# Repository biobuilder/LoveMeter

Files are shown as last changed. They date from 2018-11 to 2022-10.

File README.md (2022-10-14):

# LoveMeter
Love Meter Public Repository
Created by Damon Printz, November 11 2018

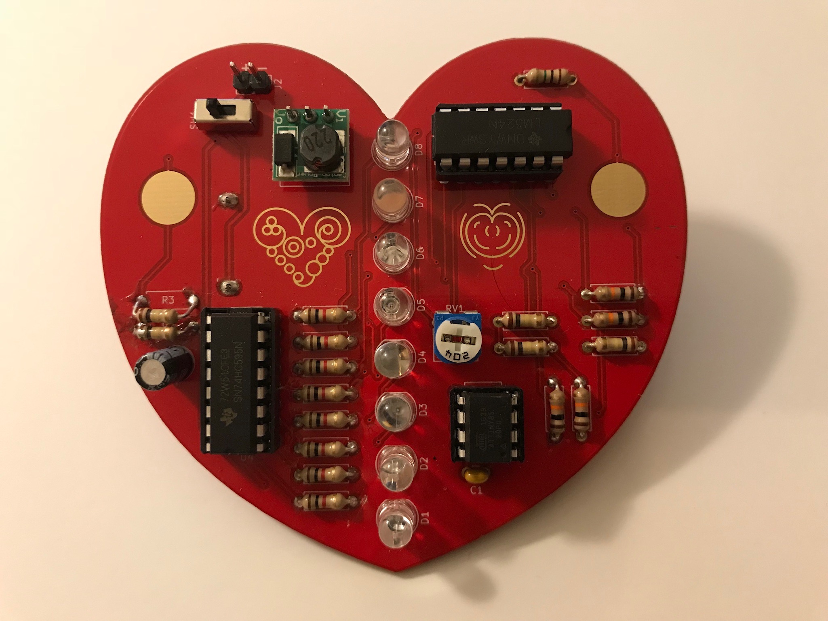
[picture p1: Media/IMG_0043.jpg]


The Love Meter is a galvanic-sensing, heart-warming educational kit for any electronic enthusiast (and their partner).  To measure love, a pair of users touch the gold-plated terminals with opposing fingers while in contact with each other.  The resulting closed circuit will measure the “conductive strength” of their feelings.  The stronger the feelings, the more LEDs will light up.  This is a very fine-tuned process, guaranteed to give you 100% accurate results.  Alternatively, if you are alone, you can see how much you love yourself.  You're at least one person you can't live without.  

Please see the Love Meter Assembly Video.
https://www.youtube.com/watch?v=fPo8kFWzP4U&t=6s

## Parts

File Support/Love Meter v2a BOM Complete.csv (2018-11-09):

Love Meter v2a Bill of Materials - Damon Printz |  |  | November 2018
ID | Designation | Value | Footprint | Part No. | Description | Manufacturer | Provider | Comment
1 | C1 | 0.1uF | 2.5mm Thru Hole | BC1072TR-ND | CAP CER 1000PF 50V X7R RADIAL | Vishay BC Components | Digikey | Ceramic Capacitor
2 | C2 | 1uF | 5mm OD x 2mm pitch | ESK105M050AC3AA | CAP ALUM 1UF 20% 50V RADIAL | KEMET | Digikey | Electrolytic Polarized Capacitor
3 | D1 | Blue | 5mm Thru Hole | WP7113QBC/D | LED BLUE CLEAR T-1 3/4 T/H | Kingbright | Digikey | 5mm, Round dome top, clear casing, 15 - 45 deg field of view, 8.5 - 8.8 mm tall, 1000 - 8000 mcd, 0 - 30 mA, < 4V Vf
4 | D2 | Green | 5mm Thru Hole | WP7113LZGCK | LED GREEN CLEAR T-1 3/4 T/H | Kingbright | Digikey
5 | D3 | Yellow | 5mm Thru Hole | WP7113SYC | LED YELLOW CLEAR T-1 3/4 T/H | Kingbright | Digikey
6 | D4 | Orange | 5mm Thru Hole | SSL-LX5093SOC | LED ORANGE CLEAR T-1 3/4 T/H | Lumex Opto/Components Inc | Digikey
7 | D5 | Red | 5mm Thru Hole | SSL-LX5093SRC/E | LED RED CLEAR T-1 3/4 T/H | Lumex Opto/Components Inc | Digikey
8 | D6 | Purple/Violet | 5mm Thru Hole | SSL-LX5093VC | LED PURPLE CLEAR T-1 3/4 T/H | Lumex Opto/Components Inc | Digikey
9 | D7 | Pink | 5mm Thru Hole | SSL-LX5093PC | LED PINK CLEAR T-1 3/4 T/H | Lumex Opto/Components Inc | Digikey
10 | D8 | White | 5mm Thru Hole | SLX-LX5093UWC/C | LED WHITE CLEAR T-1 3/4 T/H | Lumex Opto/Components Inc | Digikey
11 | J1 |  | 2x12.7mm Thru Hole | 2468 | BATTERY HOLDER AAA 2 CELL PC PIN | Keystone Electronics | Digikey | Note: May be exchanged for a AAA holder with actual wires instead of prongs
12 | J2 | DNP |  |  | DNP |  |  | Do Not Place
13 | J3 |  | 3x2.54mm | 61300311121 | CONN HEADER 3 POS 2.54 | Wurth Electronics Inc | Digikey | Headers for U1
14 | R4 | DNP |  |  | DNP |  |  | Do Not Place
15 | R1 | 1M | 6.3mm Thru Hole | CF14JT1M00 | RES 1M OHM 1/4W 5% AXIAL | Stackpole Electronics Inc | Digikey | 5% Resistor
16 | R2, R3, R5, R6 | 100k | 6.3mm Thru Hole | CF14JT100K | RES 100K OHM 1/4W 5% AXIAL | Stackpole Electronics Inc | Digikey | 5% Resistor
17 | R7, R8, R17, R18 | 10k | 6.3mm Thru Hole | CF14JT10K0 | RES 10K OHM 1/4W 5% AXIAL | Stackpole Electronics Inc | Digikey | 5% Resistor
18 | R9, R10, R11, R12, R13, R14, R15, R16 | 1k | 6.3mm Thru Hole | CF14JT1K00 | RES 1K OHM 1/4W 5% AXIAL | Stackpole Electronics Inc | Digikey | 5% Resistor
19 | RV1 | 200k | 5x5mm Thru Hole | 3306F-1-204 | TRIMMER 200K OHM 0.2W PC PIN TOP | Bourns Inc | Digikey | Trimpot Resistor
20 | SW1 |  | 3x2.54mm | EG1218 | SWITCH SLIDE SPDT 200MA 30V | E-Switch | Digikey | SPDT switch
21 | U1 |  | 3x2.54mm |  |  |  | Alibaba | 5V DC-DC Boost Regulator
22 | U2 |  | DIP-8 | ATTINY85-20PU | IC MCU 8BIT 8KB FLASH 8DIP | Microchip Technology | Digikey | Microprocessor
23 | U3 |  | DIP-14 | LM324N | IC OPAMP GP 1.2MHZ 14DIP | Texas Instruments | Digikey | Op Amps
24 | U4 |  | DIP-16 | SN74HC595N | IC 8-BIT SHIFT REGISTER 16-DIP | Texas Instruments | Digikey | Shift Register
25 | X1 |  | DIP-8 | A 08-LC-TT | CONN IC DIP SOCKET 8POS TIN | Assmann WSW Components | Digikey | IC Socket
26 | X2 |  | DIP-14 | A 14-LC-TT | CONN IC DIP SOCKET 14POS TIN | Assmann WSW Components | Digikey | IC Socket
27 | X3 |  | DIP-16 | A 16-LC-TT | CONN IC DIP SOCKET 16POS TIN | Assmann WSW Components | Digikey | IC Socket
28 | F1 |  |  | 31201527 | 3M 4008 series, 1" wide, 1/8" thick Urethane Double-Sided Tape | 3M | Grainger | Double sided foam tape
29 | F2 |  |  |  | 2 layer, FR4, Red soldermask with ENIG finish |  |  | PCB Board

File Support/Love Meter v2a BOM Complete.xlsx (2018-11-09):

Love Meter v2a Bill of Materials - Damon Printz |  |  | 2018-11-01
ID | Designation | Value | Footprint | Part No. | Description | Manufacturer | Provider | Comment
1 | C1 | 0.1uF | 2.5mm Thru Hole | BC1072TR-ND | CAP CER 1000PF 50V X7R RADIAL | Vishay BC Components | Digikey (https://www.digikey.com/product-detail/en/vishay-bc-components/K102K15X7RF5TL2/BC1072TR-ND/286526) | Ceramic Capacitor
2 | C2 | 1uF | 5mm OD x 2mm pitch | ESK105M050AC3AA | CAP ALUM 1UF 20% 50V RADIAL | KEMET | Digikey (https://www.digikey.com/product-detail/en/kemet/ESK105M050AC3AA/399-6596-ND/3083011) | Electrolytic Polarized Capacitor
3 | D1 | Blue | 5mm Thru Hole | WP7113QBC/D | LED BLUE CLEAR T-1 3/4 T/H | Kingbright | Digikey (https://www.digikey.com/product-detail/en/kingbright/WP7113QBC-D/754-1489-ND/2261460) | 5mm, Round dome top, clear casing, 15 - 45 deg field of view, 8.5 - 8.8 mm tall, 1000 - 8000 mcd, 0 - 30 mA, < 4V Vf
4 | D2 | Green | 5mm Thru Hole | WP7113LZGCK | LED GREEN CLEAR T-1 3/4 T/H | Kingbright | Digikey (https://www.digikey.com/product-detail/en/kingbright/WP7113LZGCK/754-1920-ND/5177421)
5 | D3 | Yellow | 5mm Thru Hole | WP7113SYC | LED YELLOW CLEAR T-1 3/4 T/H | Kingbright | Digikey (https://www.digikey.com/product-detail/en/kingbright/WP7113SYC/754-1280-ND/1747679)
6 | D4 | Orange | 5mm Thru Hole | SSL-LX5093SOC | LED ORANGE CLEAR T-1 3/4 T/H | Lumex Opto/Components Inc | Digikey (https://www.digikey.com/product-detail/en/lumex-opto-components-inc/SSL-LX5093SOC/67-1113-ND/270911)
7 | D5 | Red | 5mm Thru Hole | SSL-LX5093SRC/E | LED RED CLEAR T-1 3/4 T/H | Lumex Opto/Components Inc | Digikey (https://www.digikey.com/product-detail/en/lumex-opto-components-inc/SSL-LX5093SRC-E/67-1612-ND/334590)
8 | D6 | Purple/Violet | 5mm Thru Hole | SSL-LX5093VC | LED PURPLE CLEAR T-1 3/4 T/H | Lumex Opto/Components Inc | Digikey (https://www.digikey.com/products/en/optoelectronics/led-indication-discrete/105)
9 | D7 | Pink | 5mm Thru Hole | SSL-LX5093PC | LED PINK CLEAR T-1 3/4 T/H | Lumex Opto/Components Inc | Digikey
10 | D8 | White | 5mm Thru Hole | SLX-LX5093UWC/C | LED WHITE CLEAR T-1 3/4 T/H | Lumex Opto/Components Inc | Digikey (https://www.digikey.com/product-detail/en/lumex-opto-components-inc/SLX-LX5093UWC-C/67-1691-ND/754532)
11 | J1 |  | 2x12.7mm Thru Hole | 2468 | BATTERY HOLDER AAA 2 CELL PC PIN | Keystone Electronics | Digikey (https://www.digikey.com/product-detail/en/keystone-electronics/2468/36-2468-ND/303817) | Note: May be exchanged for a AAA holder with actual wires instead of prongs
12 | J2 | DNP |  |  | DNP |  |  | Do Not Place
13 | J3 |  | 3x2.54mm | 61300311121 | CONN HEADER 3 POS 2.54 | Wurth Electronics Inc | Digikey (https://www.digikey.com/product-detail/en/wurth-electronics-inc/61300311121/732-5316-ND/4846825) | Headers for U1
14 | R4 | DNP |  |  | DNP |  |  | Do Not Place
15 | R1 | 1M | 6.3mm Thru Hole | CF14JT1M00 | RES 1M OHM 1/4W 5% AXIAL | Stackpole Electronics Inc | Digikey (https://www.digikey.com/product-detail/en/stackpole-electronics-inc/CF14JT1M00/CF14JT1M00TR-ND/1741316) | 5% Resistor
16 | R2, R3, R5, R6 | 100k | 6.3mm Thru Hole | CF14JT100K | RES 100K OHM 1/4W 5% AXIAL | Stackpole Electronics Inc | Digikey (https://www.digikey.com/product-detail/en/stackpole-electronics-inc/CF14JT100K/CF14JT100KTR-ND/1741263) | 5% Resistor
17 | R7, R8, R17, R18 | 10k | 6.3mm Thru Hole | CF14JT10K0 | RES 10K OHM 1/4W 5% AXIAL | Stackpole Electronics Inc | Digikey (https://www.digikey.com/product-detail/en/stackpole-electronics-inc/CF14JT10K0/CF14JT10K0TR-ND/1741265) | 5% Resistor
18 | R9, R10, R11, R12, R13, R14, R15, R16 | 1k | 6.3mm Thru Hole | CF14JT1K00 | RES 1K OHM 1/4W 5% AXIAL | Stackpole Electronics Inc | Digikey (https://www.digikey.com/product-detail/en/stackpole-electronics-inc/CF14JT1K00/CF14JT1K00TR-ND/1741314) | 5% Resistor
19 | RV1 | 200k | 5x5mm Thru Hole | 3306F-1-204 | TRIMMER 200K OHM 0.2W PC PIN TOP | Bourns Inc | Digikey (https://www.digikey.com/product-detail/en/bourns-inc/3306F-1-204/3306F-204-ND/84718) | Trimpot Resistor
20 | SW1 |  | 3x2.54mm | EG1218 | SWITCH SLIDE SPDT 200MA 30V | E-Switch | Digikey (https://www.digikey.com/product-detail/en/e-switch/EG1218/EG1903-ND/101726) | SPDT switch
21 | U1 |  | 3x2.54mm |  |  |  | Alibaba (https://wholesaler.alibaba.com/product-detail/1-5V-1-8V-2-5V_60591555129.html) | 5V DC-DC Boost Regulator
22 | U2 |  | DIP-8 | ATTINY85-20PU | IC MCU 8BIT 8KB FLASH 8DIP | Microchip Technology | Digikey (https://www.digikey.com/product-detail/en/microchip-technology/ATTINY85-20PU/ATTINY85-20PU-ND/735469) | Microprocessor
23 | U3 |  | DIP-14 | LM324N | IC OPAMP GP 1.2MHZ 14DIP | Texas Instruments | Digikey (https://www.digikey.com/product-detail/en/texas-instruments/LM324N/296-1391-5-ND/277627) | Op Amps
24 | U4 |  | DIP-16 | SN74HC595N | IC 8-BIT SHIFT REGISTER 16-DIP | Texas Instruments | Digikey (https://www.digikey.com/product-detail/en/texas-instruments/SN74HC595N/296-1600-5-ND/277246) | Shift Register
25 | X1 |  | DIP-8 | A 08-LC-TT | CONN IC DIP SOCKET 8POS TIN | Assmann WSW Components | Digikey (https://www.digikey.com/product-detail/en/assmann-wsw-components/A-08-LC-TT/AE9986-ND/821740) | IC Socket
26 | X2 |  | DIP-14 | A 14-LC-TT | CONN IC DIP SOCKET 14POS TIN | Assmann WSW Components | Digikey (https://www.digikey.com/product-detail/en/assmann-wsw-components/A-14-LC-TT/AE9989-ND/821743) | IC Socket
27 | X3 |  | DIP-16 | A 16-LC-TT | CONN IC DIP SOCKET 16POS TIN | Assmann WSW Components | Digikey (https://www.digikey.com/product-detail/en/assmann-wsw-components/A-16-LC-TT/AE9992-ND/821746) | IC Socket
28 | F1 |  |  | 31201527 | 3M 4008 series, 1" wide, 1/8" thick Urethane Double-Sided Tape | 3M | Grainger (https://www.grainger.com/product/3M-Urethane-Foam-Double-Sided-15C142) | Double sided foam tape
29 | F2 |  |  |  | 2 layer, FR4, Red soldermask with ENIG finish |  |  | PCB Board

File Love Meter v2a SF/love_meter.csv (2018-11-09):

Id | Designator | Package | Quantity | Designation | Supplier and ref
1 | J1 | 2xAAA_PCB | 1 | AAA_hldr
2 | U1 | 3pin5vReg | 1 | 5VReg
3 | SW1 | Pin_Header_Straight_1x03_Pitch2.54mm | 1 | SW_SPDT
4 | RV1 | Potentiometer_Trimmer_ACP_CA6v_Horizontal | 1 | 200K TRIMPOT
5 | R18,R17,R8,R7 | R_Axial_DIN0207_L6.3mm_D2.5mm_P7.62mm_Horizontal | 4 | 10K
6 | R16,R15,R14,R13,R12,R11,R10,R9 | R_Axial_DIN0207_L6.3mm_D2.5mm_P7.62mm_Horizontal | 8 | 1K
7 | R6,R5,R4,R3,R2 | R_Axial_DIN0207_L6.3mm_D2.5mm_P7.62mm_Horizontal | 5 | 100K
8 | R1 | R_Axial_DIN0207_L6.3mm_D2.5mm_P7.62mm_Horizontal | 1 | 1M
9 | J3,J4 | GALV_PAD | 2 | TEST_1P
10 | D8,D7,D6,D5,D4,D3,D2,D1 | LED_D5.0mm | 8 | LED
11 | C1 | C_Disc_D3.0mm_W1.6mm_P2.50mm | 1 | 0.1uF
12 | C2 | CP_Radial_D5.0mm_P2.00mm | 1 | 1uF
13 | J2 | Pin_Header_Straight_1x02_Pitch2.54mm | 1 | bat_con
14 | U2 | DIP-8_W7.62mm | 1 | ATTINY85-20PU
15 | U3 | DIP-14_W7.62mm_LongPads | 1 | LM324
16 | U4 | DIP-16_W7.62mm_LongPads | 1 | 74HC595

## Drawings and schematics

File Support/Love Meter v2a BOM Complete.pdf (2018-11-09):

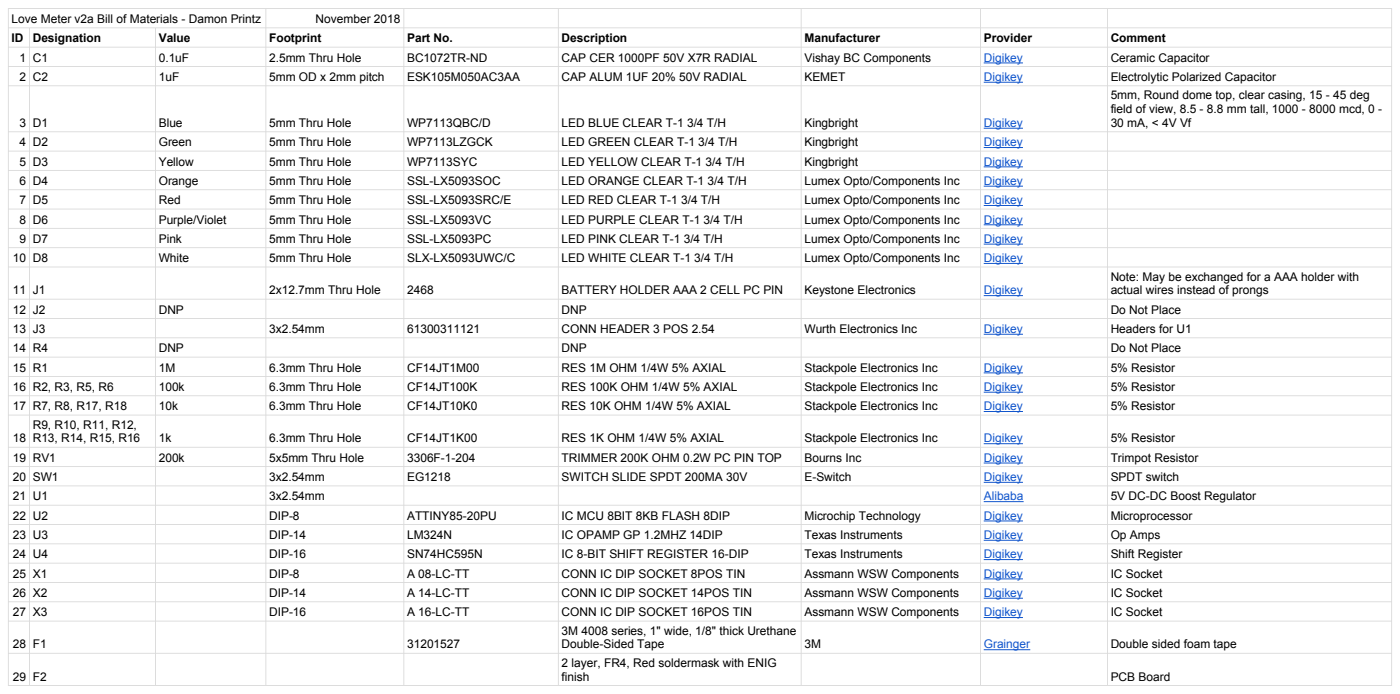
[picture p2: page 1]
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

Note: May be exchanged for a AAA holder with
actual wires instead of prongs

3M 4008 series, 1" wide, 1/8" thick Urethane
2 layer, FR4, Red soldermask with ENIG

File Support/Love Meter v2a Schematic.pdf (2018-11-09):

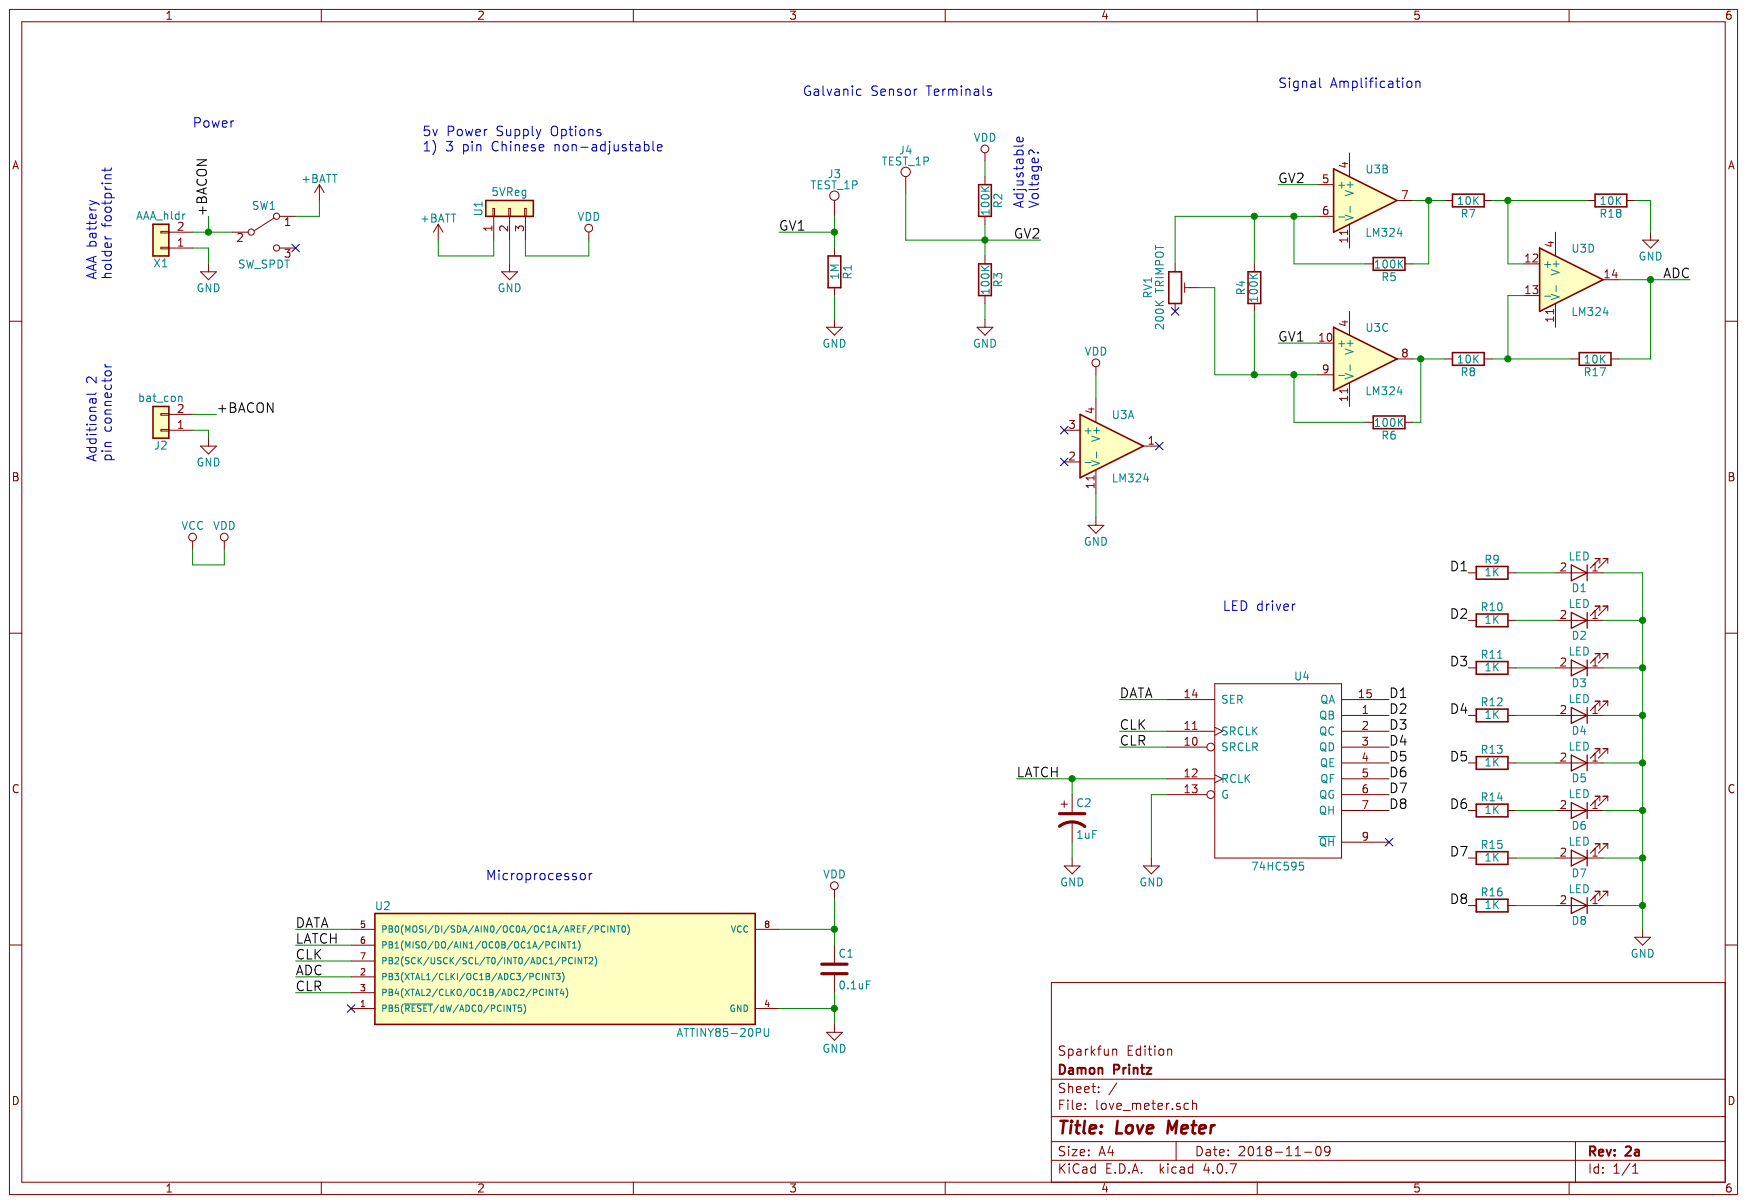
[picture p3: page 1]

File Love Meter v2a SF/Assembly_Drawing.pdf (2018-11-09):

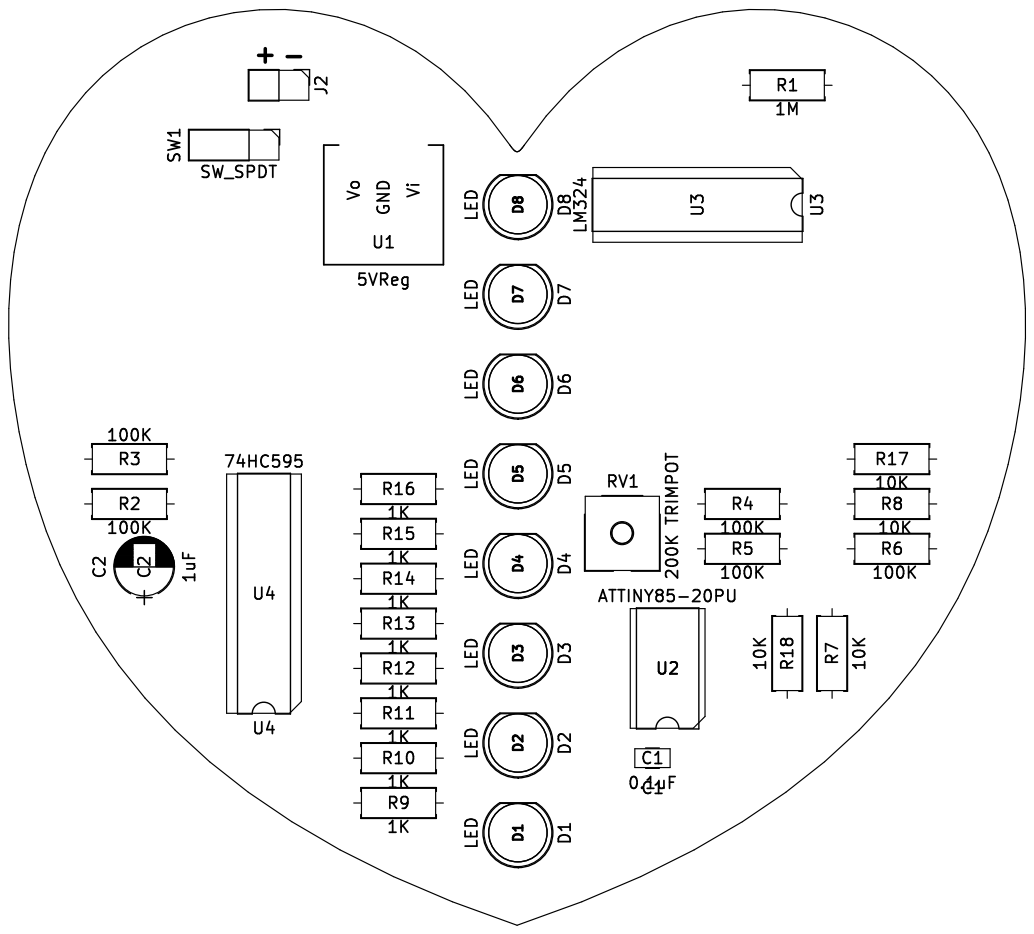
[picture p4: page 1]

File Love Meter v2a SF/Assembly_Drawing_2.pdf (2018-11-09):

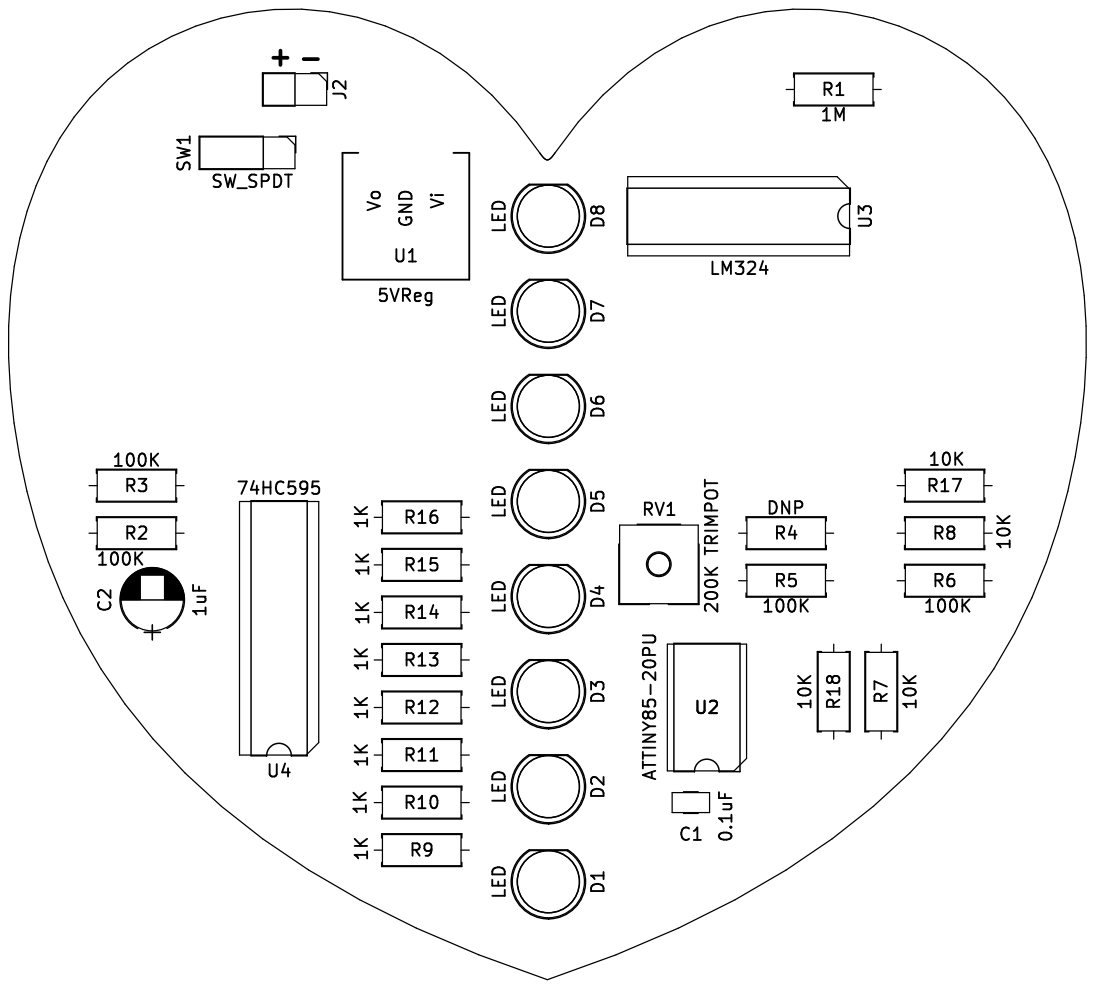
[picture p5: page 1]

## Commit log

2018-11-09 Added KiCAD Project Files
    [love_meter.csv, love_meter.kicad_pcb, love_meter.sch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]
2018-11-09 Added additional library support and Gerber files
    Note: Please reference the Sparkfun Aesthetics libary (https://github.com/sparkfun/SparkFun-KiCad-Libraries/tree/master/Footprints/Aesthetics.pretty)
    [love_meter-B.Cu.gbr, love_meter-B.Mask.gbr, love_meter-B.Paste.gbr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]
2018-11-09 Added BOM and Schematic in easy formats
    [Love Meter v2a BOM Complete.csv, Love Meter v2a BOM Complete.xlsx]
